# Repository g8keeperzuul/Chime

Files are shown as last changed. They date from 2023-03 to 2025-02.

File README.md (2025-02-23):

# Chime : A Home Assistant Siren Implementation #

## Description ##

The **Chime** is the second half of the smart doorbell project. However, the Chime (or Siren in Home Assistant nomanclature) can exist independently of the Doorbell. Any home automation task that can benefit from an alarm or audio annoucement and display some status information would find a use for the Chime.

The doorbell essentially provides a button to trigger an action in Home Assistant. Through the magic of some scripted automation, HA then commands the Chime to make a doorbell sound. The doorbell and chimer are two separate independent projects which rely on HA to work together.

Of course, the chime need not be limited to doorbell only activities. Since it can play a variety of tones, or in fact any audio file, the Chime can also be used as a fire/smoke alarm and security siren. It can even welcome you home if you're using presence detection. 

_This project will detail the build of the Chime, a Home Assistant Siren implementation._

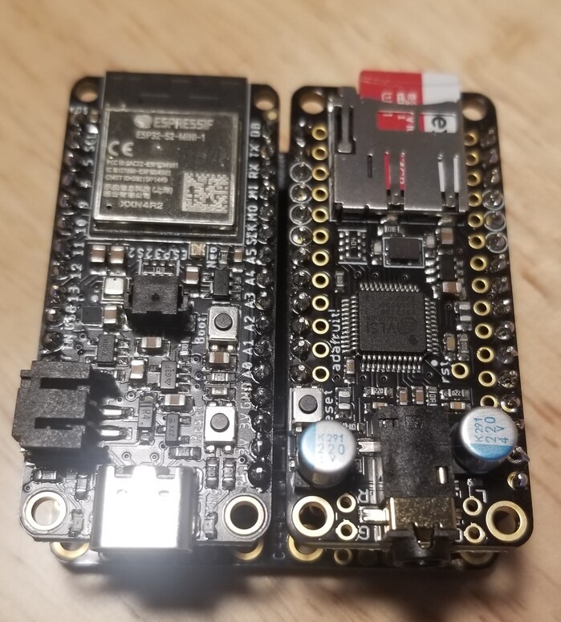
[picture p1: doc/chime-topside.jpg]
Chime top


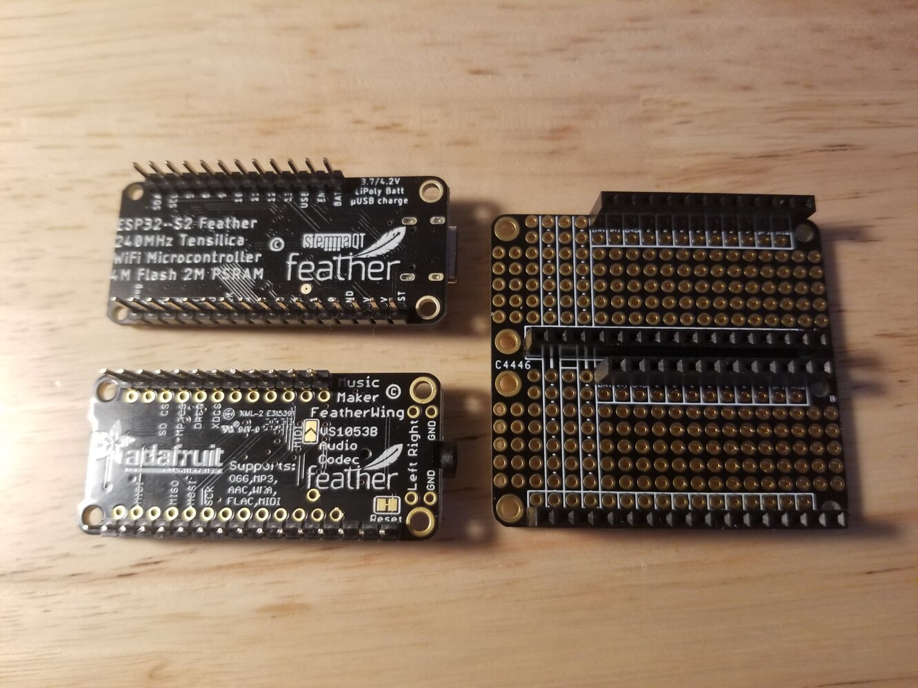
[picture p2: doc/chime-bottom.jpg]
Chime bottom


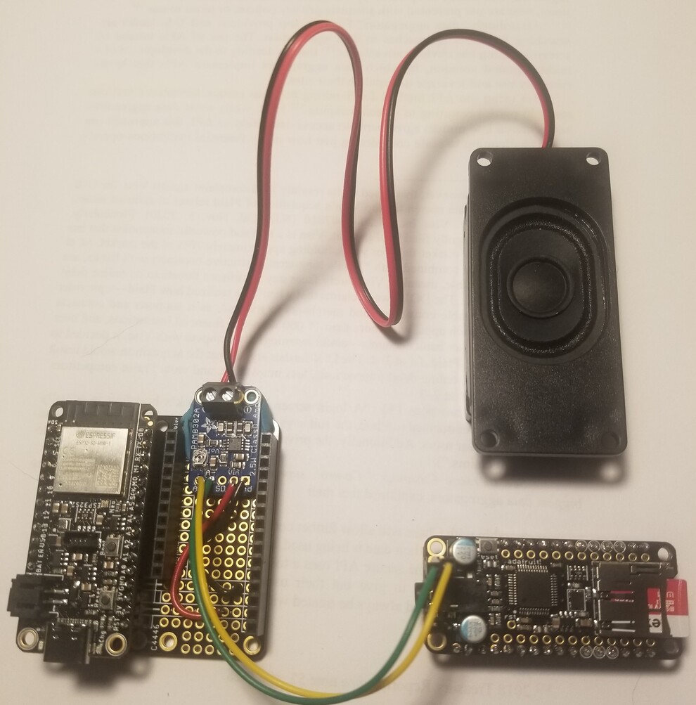
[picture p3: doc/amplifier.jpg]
Amp and Speaker


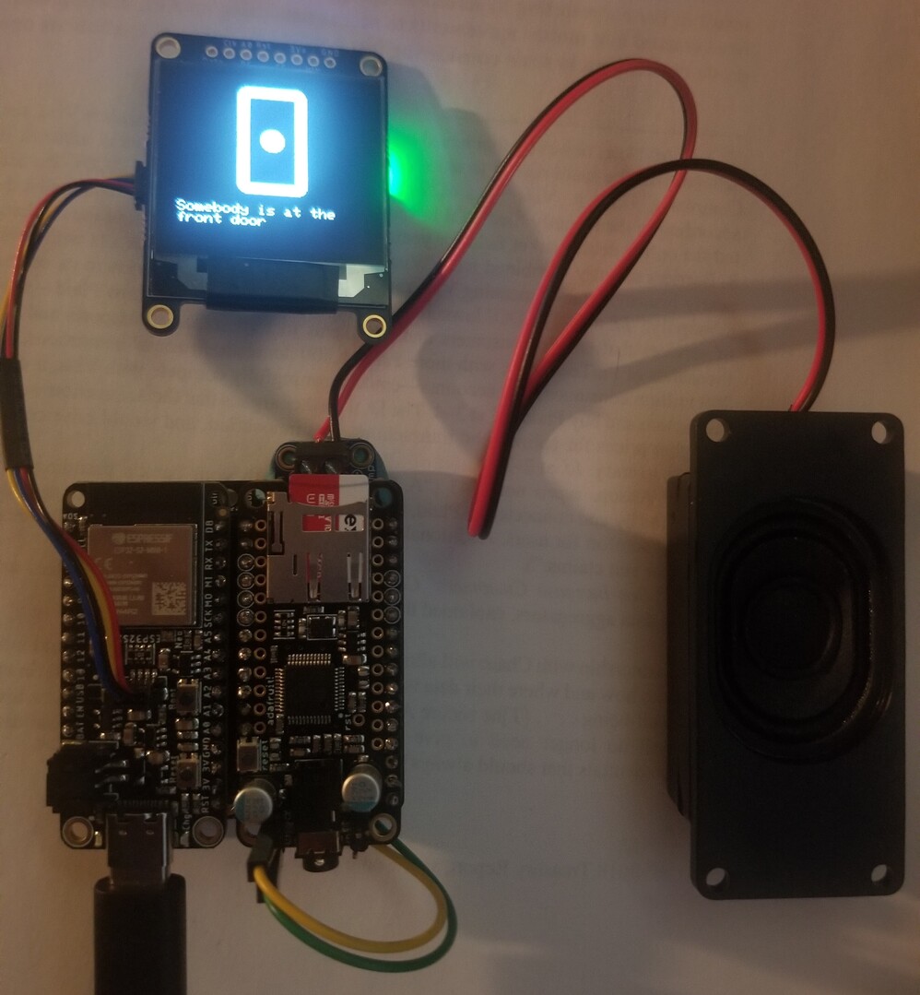
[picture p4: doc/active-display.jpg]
Active display


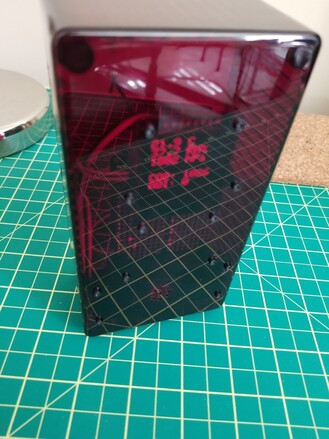
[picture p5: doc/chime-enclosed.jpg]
Chime enclosure


## Parts List ##
| Component | Description |
| -- | -- |
| [Adafruit ESP32-S2 Feather with BME280](https://www.adafruit.com/product/5303) | An ESP32-S2 with 4MB Flash and 2MB PSRAM on a Feather format breakout. The BME280 temperature/humidity/pressure sensor is not necessary |
| [Adafruit MusicMaker Featherwing](https://www.adafruit.com/product/3357) | A Feather format breakout for the VS1053B, an encoding/decoding (codec) chip that can decode a wide variety of audio formats such as MP3, AAC, Ogg Vorbis, WMA, MIDI, FLAC, WAV (PCM and ADPCM) | 
| [FeatherWing Doubler](https://www.adafruit.com/product/2890) | Not strictly necessary since the two above Feather-formatted boards can be stacked on top of each other. However the FeatherWing Doubler with its side-by-side layout just allows easier access to buttons and SD card |
| [Adafruit Grayscale 1.5" 128x128 OLED Display](https://www.adafruit.com/product/4741)|An I2C enabled OLED 128x128 pixel display|
| [Adafruit Mono 2.5W Class D Audio Amplifier - PAM8302](https://www.adafruit.com/product/2130) | A 2.5 watt audio amplifier. |
| [Mono Enclosed Speaker - 3W 4 Ohm](https://www.adafruit.com/product/3351) | A simple speaker |

### Pin Mapping ###
When both the microcontroller and codec are on Feather breakouts, you simply stack one on top of the other and all the proper pins align. However, in case you don't have the convenience of having both components in a Feather breakout format, the pin connections between the microcontroller and codec are specified below:
| ESP32-S2 GPIO pins | MusicMaker IO pins | DEFINE (chime.h) | PAM8302 |
| -- | -- | -- | -- |
| 10 | XDCS (command/data select) | VS1053_DCS | |
| 9 (hardware interrupt capable pin - they all are on the ESP32)| DREQ (data request) | VS1053_DREQ | |
| 6 | VS1053 select | VS1053_CS | |
| 5 | SDCS (sdcard select) | CARDCS | |
| 36 (SCK) | SCK | | |
| 35 (MO) | MOSI | | |
| 37 (MI) | MISO | | |
| | G(round) near headphone jack | | A- |
| | R(ight) near headphone jack | | A+ |

## Assembly ##
Placing the ESP32-S2 Feather and MusicMaker onto the FeatherWing Doubler as well as plugging in the I2C display is all plug-and-go.
I should have bought the [version of the MusicMaker without the headphone jack](https://www.adafruit.com/product/3436) that can be connected directly to speakers (if you use this, you can forego the separate PAM8302 amplifier). As a work-around, I added the PAM8302 based audio amplifier which as you can see from the photos is blue-tacked beneath the MusicMaker, connected to 3.3V and ground as well as one of the channel outputs (to support stereo another PAM8302 amplifier and speaker would be required).

## SDCard ##
Format as FAT16 or FAT32. Create a directory to store all the tones you intend on using. The filenames will need to be in 8.3 format. The default directory is /tones (defined in chime.h). This directory should *ONLY* contain audio files that are compatible with the VS1053B codec (Ogg Vorbis, MP3/MP2/MP1, MP4, AAC, WMA, FLAC, WAV (PCM and ADPCM)). 

## MQTT Discovery ##
The Chime publishes several MQTT discovery messages upon startup.
The main one describes the [**siren**](https://www.home-assistant.io/integrations/siren.mqtt/) entity, providing the command topic to send messages to for activation/deactivation. Siren features such as duration, volume and available tones are also defined.
Available tones is dynamically populated with all files found in the /tones directory on the SD card. Calling the Siren service in Home Assistant will only allow one of the available tones to be set. 

### Siren: ###
Discovery topic: homeassistant/siren/featheresp32s2/chime/config
```
{
  "entity_category": "config",
  "unit_of_measurement": "",
  "availability_topic": "homeassistant/siren/featheresp32s2/availability",
  "unique_id": "featheresp32s2_chime",
  "device": {
    "name": "Chime",
    "identifiers": "84:F7:03:D6:8B:20",
    "mf": "Adafruit",
    "mdl": "Feather ESP32-S2 with BME280",
    "sw": "20230304.1700"
  },
  "name": "featheresp32s2 chime",
  "icon": "mdi:bullhorn",
  "state_topic": "homeassistant/siren/featheresp32s2/state",
  "command_topic": "homeassistant/siren/featheresp32s2/command",
  "optimistic": false,
  "support_duration": false,
  "support_volume_set": true,
  "available_tones": [
    "alarm.mp3",
    "alarm.wav",
    "bell.wav",
    "doorbell.wav",
    "siren001.wav",
    "siren002.wav",
    "siren003.wav"
  ]
}
```
Note that the "featheresp32s2" part of all the topics can be changed by editing DEVICE_ID in chime.h

### Text: ###
The [**text**](https://www.home-assistant.io/integrations/text.mqtt/) integration was just recently (Dec 2022) introduced. Be sure to update Home Assistant for support.

Discovery topic: homeassistant/text/featheresp32s2/display/config
```
{
  "entity_category": "config",
  "unit_of_measurement": "",
  "availability_topic": "homeassistant/siren/featheresp32s2/availability",
  "unique_id": "featheresp32s2_display",
  "device": {
    "name": "Chime",
    "identifiers": "84:F7:03:D6:8B:20",
    "mf": "Adafruit",
    "mdl": "Feather ESP32-S2 with BME280",
    "sw": "20230317.0900"
  },
  "name": "featheresp32s2 display",
  "icon": "mdi:image-text",
  "state_topic": "homeassistant/text/featheresp32s2/display/state",
  "command_topic": "homeassistant/text/featheresp32s2/display/command",
  "command_template": "{ 'text': '{{ value }}', 'graphic': 'NONE' }",
  "value_template": "{{ value_json.text }}"
}
```

Chime publishes some diagnostic information periodically, namely wifi related details such as RSSI value (measurable), IP and MAC addresses (static) to the topic *homeassistant/siren/featheresp32s2/diagnostics*

The diagnostic message is simply:
```
{
  "wifi_rssi": -50,
  "wifi_ip": "10.0.0.177",
  "wifi_mac": "84:F7:03:D6:8B:20",
  "last_boot": "2023-03-17T12:42:13-0400"
}
```

The MQTT discovery message for RSSI looks like this:
```
{
  "state_class": "measurement",
  "entity_category": "diagnostic",
  "availability_topic": "homeassistant/siren/featheresp32s2/availability",
  "unique_id": "featheresp32s2_wifi_rssi",
  "device": {
    "name": "Chime",
    "ids": "84:F7:03:D6:8B:20"
  },
  "name": "featheresp32s2 wifi_rssi",
  "icon": "mdi:wifi-strength-2",
  "state_topic": "homeassistant/siren/featheresp32s2/diagnostics",
  "value_template": "{{ value_json.wifi_rssi }}"
}
```
(last boot, IP and MAC discovery messages not shown)

The **refresh rate** is the frequency (in minutes) what the diagnostic information is updated.
The refresh rate can be set and it is made discoverable through the following message:

```
{
  "entity_category": "config",
  "unit_of_measurement": "minutes",
  "availability_topic": "homeassistant/siren/featheresp32s2/availability",
  "unique_id": "featheresp32s2_refreshrate",
  "device": {
    "name": "Chime",
    "identifiers": "84:F7:03:D6:8B:20",
    "mf": "Adafruit",
    "mdl": "Feather ESP32-S2 with BME280",
    "sw": "20230304.1700"
  },
  "name": "featheresp32s2 refreshrate",
  "icon": "mdi:refresh-circle",
  "state_topic": "homeassistant/number/featheresp32s2/refreshrate/get",
  "command_topic": "homeassistant/number/featheresp32s2/refreshrate/set",
  "min": 1,
  "max": 60,
  "step": 1
}
```

# Usage #

Once configured, the Chime should announce itself to Home Assistant without any further effort and be ready to incorporate into your automation scripts.

1. Copy sample-env.h to env.h and customize env.h and chime.h to match your environment.
2. (Optional) #define DISABLE_SERIAL_OUTPUT 1 in log.h to disable all serial logging. Best to keep logging enabled until everything is confirmed working. 
3. Compile and upload firmware to your device.
4. Format an SDcard with FAT16 or FAT32. Create a directory named **/tones** and copy some mp3 or wav files (using 8.3 filenames) into the directory. Insert the SDcard into the MusicMaker.
5. Power on device. Confirm through MQTT explorer that new discovery topics exist and that device is visible to Home Assistant.
6. Using *Home Assistant > Developer Tools > Services*, activate the siren. Note that only a tone listed in **available_tones** in the siren discovery message is allowed.

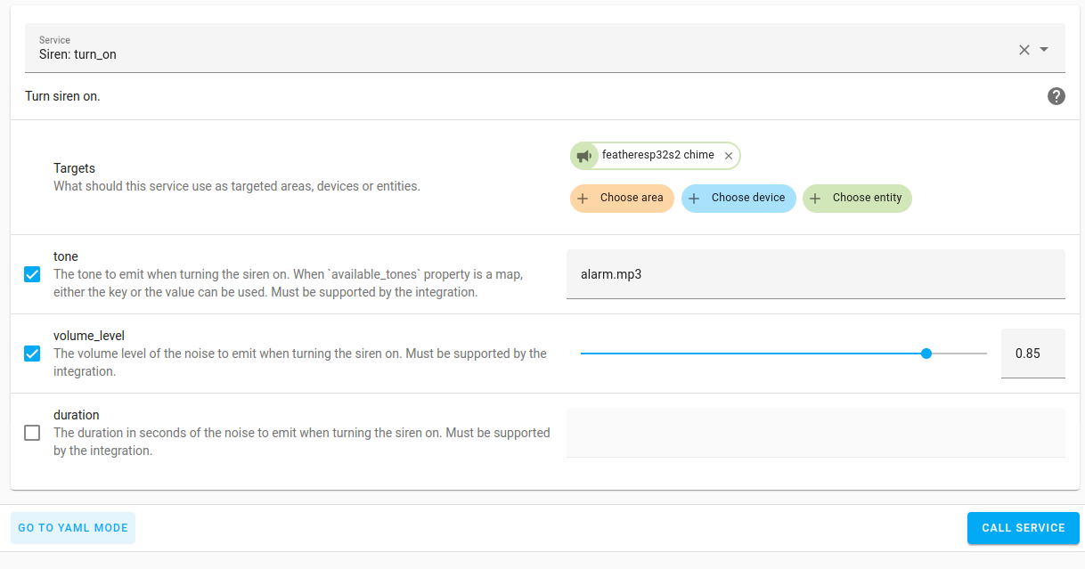
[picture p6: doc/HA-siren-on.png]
Activate Siren Service in HA


7. Alternatively publishing a message to MQTT will also turn the siren on and off: 
   
   *homeassistant/siren/featheresp32s2/command*
   ```
   {"state": "ON", "tone": "alarm.mp3", "volume_level": 0.5}
   {"state": "OFF"}
   ```
   where **volume_level** is a number between 0..1

   Received commands are reflected back to the state topic: 
   *homeassistant/siren/featheresp32s2/state*
  
8. The display is updated independently of the Siren.
 
  [Supported graphics](include/graphics.h) are: 
  | Label | Suggested Purpose | Graphic |
  | -- | -- | -- |
  | FIRE | Fire or smoke alarm |Fire |
  | WATER | Water leak | Water |
  | CO2 | Unsafe carbon dioxide levels | CO2 |
  | GAS | Unsafe gas detected | Gas |
  | AQI | Dirty air/particulate levels unsafe | CO2 |
  | ALERT | General alert | Alert |
  | DOOR | Doorbell ringer | Door |
  | GARAGE | Garage door ajar | Garage |
  | INFO | Informational | Info |
  | RADS | Unsafe radiation levels | Rads |
  | SAFE | Security alert | Safe |
  | FREEZE | Freeze warning | Freeze |

   *homeassistant/text/featheresp32s2/display/command*
   ```
    {"text": "Master bedroom carbon dioxide levels too high!", "graphic": "CO2" }

    {"text": "", "graphic": "NONE" } (for a blank screen)

    {"text": "...", "graphic": "MEDIUM_TEXT" } (for 10 characters, 6 lines)

    {"text": "...", "graphic": "LARGE_TEXT" } (for 7 characters, 5 lines)
   ```
## Customizing Graphics ##

1. Find something a [Material Design Icon](https://pictogrammers.com/library/mdi/) you like.
2. Edit the icon, by sizing it (remember the display maximum is 128x128) and setting a solid black background and white foreground colors.
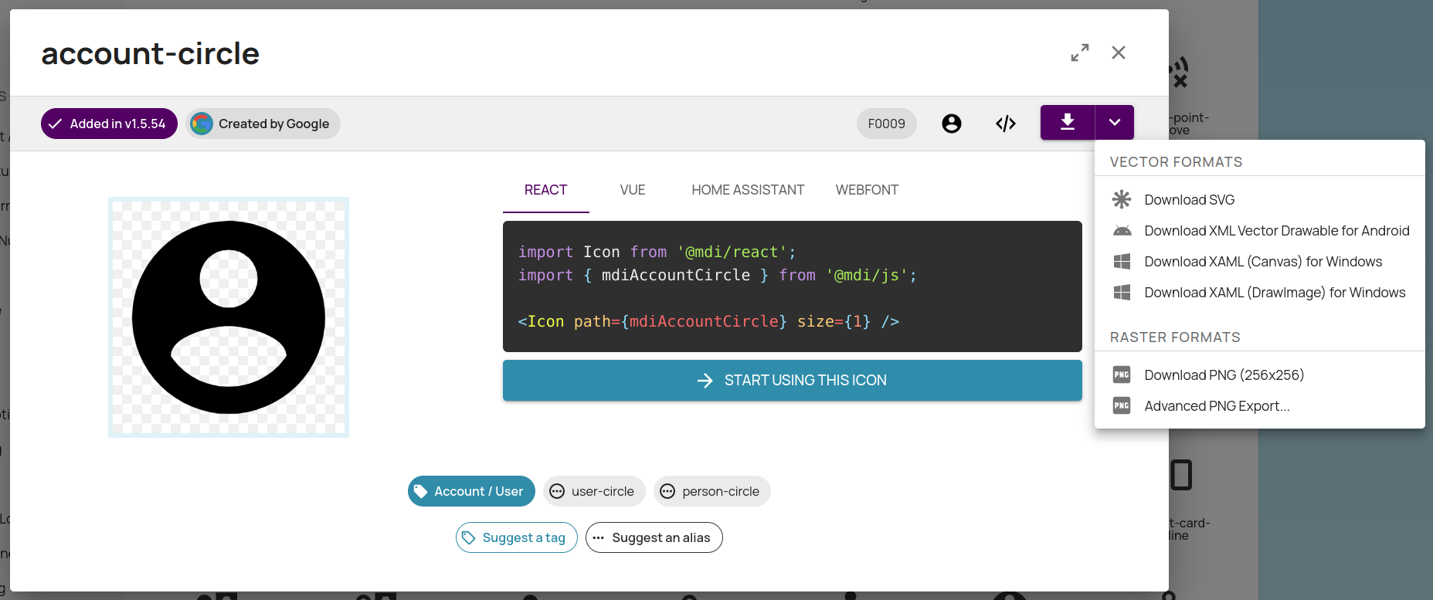
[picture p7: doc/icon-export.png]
Select icon for export
   
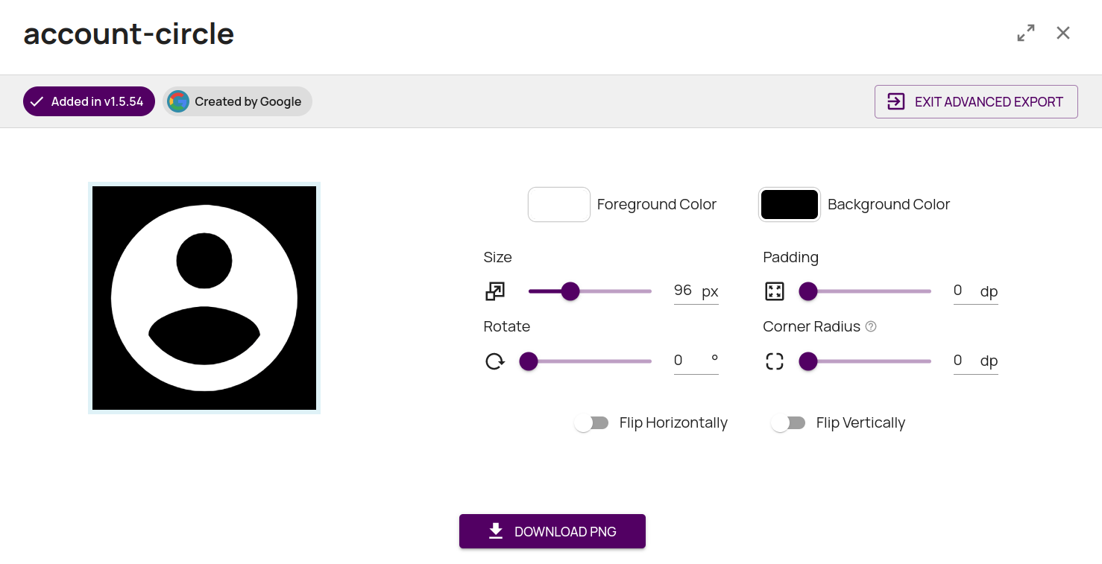
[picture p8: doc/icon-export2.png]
Edit icon
   
3. Once the graphic is created and available locally, you can upload it to a [website](https://notisrac.github.io/FileToCArray/) that will create a binary array for you.

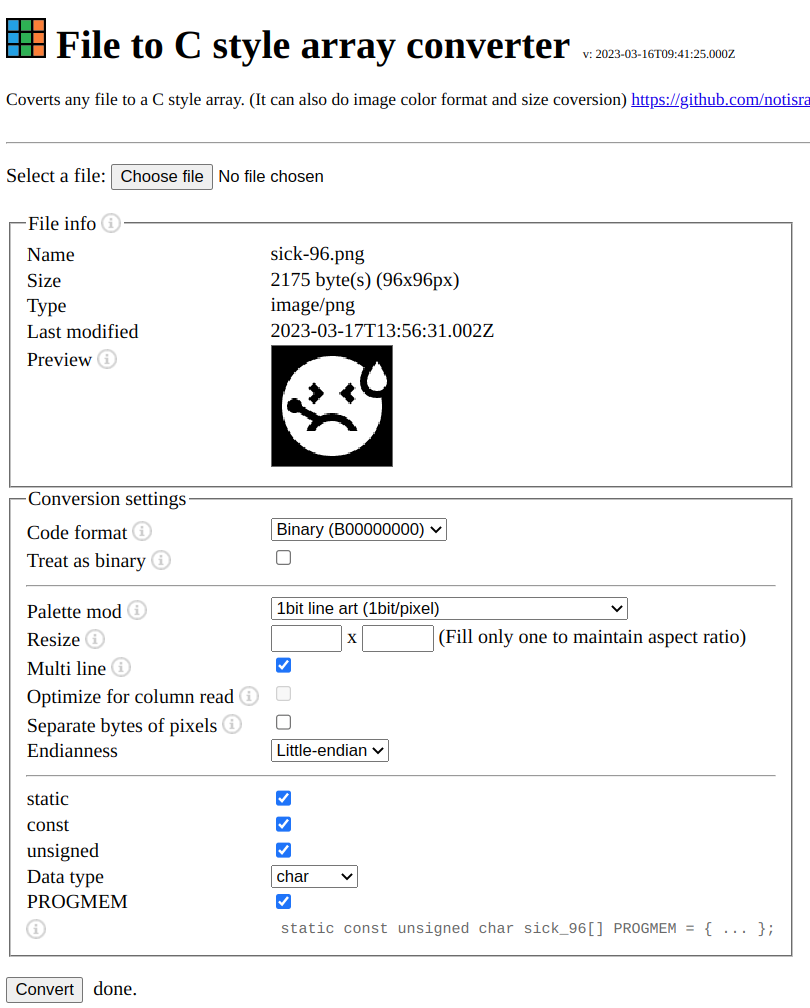
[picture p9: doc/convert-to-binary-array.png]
Create binary array

  
  The resulting output can be pasted directly into the [code](include/graphics.h).

## Home Assistant Integration ##

Of course the Chime integrates with HA using MQTT Discovery messages. However this section discusses how HA acts as the glue between the doorbell and the chime, so that pressing the doorbell button ultimately results in a ring tone sounded by the chime. 
The doorbell project captures a photo and uploads it to HA. This state update can be used as a trigger for an HA automation. Notice that the action associated with this trigger is a script.

In **automations.yaml**:
```

- id: "DOORBELL_ACTIVATED"
  alias: "Doorbell activated"
  description: "Trigger doorbell tone on Siren when Doorbell activated"
  trigger:
    - entity_id: camera.doorbell_snapshot      
      platform: state
      attribute: file_path # trigger on any change to attribute
  condition: []
  action:
    service: script.doorbell_activated
```

The script can be thought of as simply a macro for some grouped activities.

In **scripts.yaml**:
```
doorbell_activated:
  alias: Doorbell pressed
  icon: mdi:doorbell
  description: Plays the doorbell tone and displays the doorbell message, cleared
    after 1 minute
  mode: queued
  max: 5
  max_exceeded: info
  sequence:
  - alias: Display doorbell ringing message
    service: mqtt.publish
    data:
      topic: homeassistant/text/featheresp32s2/display/command
      retain: false
      payload: '{"text":"Somebody is at the   front door", "graphic": "DOOR" }'
  - alias: Play doorbell tone
    service: mqtt.publish
    data:
      topic: homeassistant/siren/featheresp32s2/command
      retain: false
      payload: '{"state":"ON", "tone": "doorbell.wav", "volume_set": 0.75 }'
  - alias: Doorbell notification
    service: notify.notify
    data:
      message: Doorbell rung!
  - alias: Wait
    delay:
      minutes: 1
  - alias: Clear display
    service: mqtt.publish
    data:
      topic: homeassistant/text/featheresp32s2/display/command
      retain: false
      payload: '{"text":"", "graphic": "NONE" }'
  ```
### Sequence Diagram ###

This sequence illustrates how both the Doorbell project and Chime project work together through Home Assistant automation. 

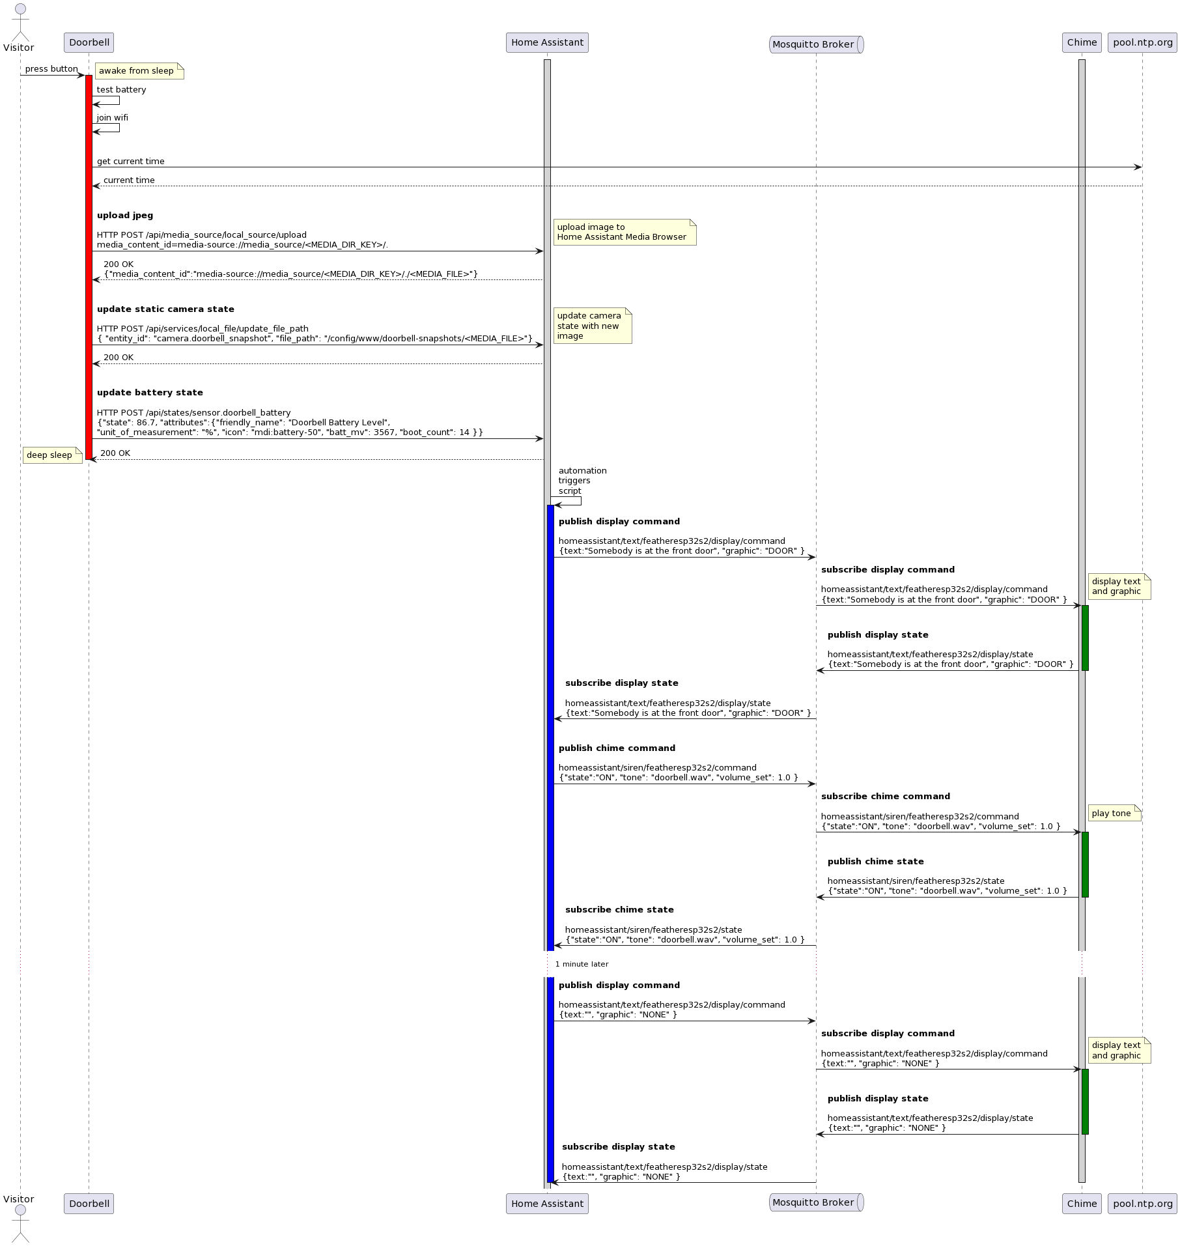
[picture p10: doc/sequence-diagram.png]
Doorbell + Chime flow

Generated using [PlantUML](https://www.plantuml.com/plantuml/png/rLLHRzis47xdhpYes5jZfUtQ3KONj5qoD6WJ5sqmO801WPBE4bkHLCYJFIF9Vnz9IL6apKk303Ec9_FutTrttntFRonnGusi6ECPQGFjzxkmOZY5ZrjOjrPMEnUHYPe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)

**PlantUML for Sequence Diagram**
```
@startuml

actor       Visitor            as visitor
participant Doorbell           as doorbell
participant "Home Assistant"   as ha
queue       "Mosquitto Broker" as mqtt
participant Chime              as chime
participant pool.ntp.org       as ntp

activate ha #lightgray
activate chime #lightgray

visitor -> doorbell : press button 
note right
awake from sleep
end note
activate doorbell #red

doorbell -> doorbell : test battery
doorbell -> doorbell : join wifi

|||
doorbell -> ntp : get current time
ntp --> doorbell : current time
|||

doorbell -> ha : <b>upload jpeg\n\nHTTP POST /api/media_source/local_source/upload\nmedia_content_id=media-source://media_source/<MEDIA_DIR_KEY>/.
note right
upload image to
Home Assistant Media Browser
end note

ha --> doorbell : 200 OK\n{"media_content_id":"media-source://media_source/<MEDIA_DIR_KEY>/./<MEDIA_FILE>"}
|||
doorbell -> ha : <b>update static camera state\n\nHTTP POST /api/services/local_file/update_file_path\n{ "entity_id": "camera.doorbell_snapshot", "file_path": "/config/www/doorbell-snapshots/<MEDIA_FILE>"}
note right
update camera
state with new 
image
end note
ha --> doorbell : 200 OK
|||
doorbell -> ha : <b>update battery state\n\nHTTP POST /api/states/sensor.doorbell_battery\n{"state": 86.7, "attributes":{"friendly_name": "Doorbell Battery Level",\n"unit_of_measurement": "%", "icon": "mdi:battery-50", "batt_mv": 3567, "boot_count": 14 }}
ha --> doorbell : 200 OK
deactivate doorbell

note left
deep sleep
end note

ha -> ha : automation\ntriggers\nscript
activate ha #blue

ha -> mqtt : <b>publish display command\n\nhomeassistant/text/featheresp32s2/display/command\n{text:"Somebody is at the front door", "graphic": "DOOR" }

mqtt -> chime : <b>subscribe display command\n\nhomeassistant/text/featheresp32s2/display/command\n{text:"Somebody is at the front door", "graphic": "DOOR" }
activate chime #green
note right
display text
and graphic
end note
|||
chime -> mqtt : <b>publish display state\n\nhomeassistant/text/featheresp32s2/display/state\n{text:"Somebody is at the front door", "graphic": "DOOR" }

deactivate chime

mqtt -> ha : <b>subscribe display state\n\nhomeassistant/text/featheresp32s2/display/state\n{text:"Somebody is at the front door", "graphic": "DOOR" }
|||
ha -> mqtt : <b>publish chime command\n\nhomeassistant/siren/featheresp32s2/command\n{"state":"ON", "tone": "doorbell.wav", "volume_set": 1.0 }

mqtt -> chime : <b>subscribe chime command\n\nhomeassistant/siren/featheresp32s2/command\n{"state":"ON", "tone": "doorbell.wav", "volume_set": 1.0 }
activate chime #green
note right
play tone
end note
|||
chime -> mqtt : <b>publish chime state\n\nhomeassistant/siren/featheresp32s2/state\n{"state":"ON", "tone": "doorbell.wav", "volume_set": 1.0 }

deactivate chime

mqtt -> ha : <b>subscribe chime state\n\nhomeassistant/siren/featheresp32s2/state\n{"state":"ON", "tone": "doorbell.wav", "volume_set": 1.0 }

...1 minute later...

ha -> mqtt : <b>publish display command\n\nhomeassistant/text/featheresp32s2/display/command\n{text:"", "graphic": "NONE" }

mqtt -> chime : <b>subscribe display command\n\nhomeassistant/text/featheresp32s2/display/command\n{text:"", "graphic": "NONE" }
activate chime #green
note right
display text
and graphic
end note
|||
chime -> mqtt : <b>publish display state\n\nhomeassistant/text/featheresp32s2/display/state\n{text:"", "graphic": "NONE" }

deactivate chime

mqtt -> ha : <b>subscribe display state\n\nhomeassistant/text/featheresp32s2/display/state\n{text:"", "graphic": "NONE" }

deactivate chime
deactivate chime

deactivate ha

@enduml
```

## Display Continuous Updates using Home Assistant Automation ##

Rather than only show alerts or events (like a doorbell press), Chime can also be used to continuously display sensor updates.
In this example, environmental sensors from the [AirMonitor project](https://github.com/g8keeperzuul/AirMonitor) are displayed on Chime as they are updated.
The Chime display is updated via a message published to MQTT with the various sensor values used as parameters to the message body.

```
alias: Update Chime on Air Monitor
description: Display Air Monitor (featherM0) status on Chime
trigger:
  - platform: state
    entity_id:
      - sensor.featherm0_aqi
      - sensor.featherm0_carbon_dioxide
      - sensor.featherm0_humidity
      - sensor.featherm0_pressure
      - sensor.featherm0_temperature
condition: []
action:
  - service: mqtt.publish
    data:
      qos: 0
      retain: false
      topic: homeassistant/text/featheresp32s2/display/command
      payload: >-
        { "text": "{{states('sensor.featherm0_temperature')|round(1)}}
        C\n{{states('sensor.featherm0_humidity')|round(1)}}
        RH%\n{{states('sensor.featherm0_pressure')|round()}} hPa\n\nCO2:
        {{states('sensor.featherm0_carbon_dioxide')}}\nAQI:
        {{states('sensor.featherm0_aqi')}}", "graphic": "MEDIUM_TEXT" }
mode: single
```
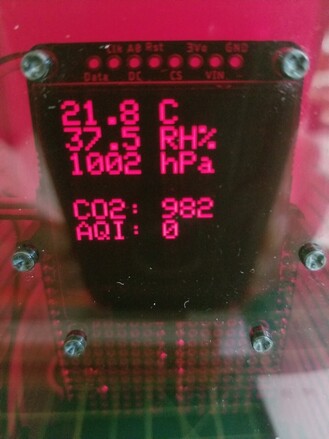
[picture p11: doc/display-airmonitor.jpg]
Chime displaying AirMonitor results


## Display Continuous Updates without Home Assistant ##

The Chime is a dumb device that has no sensors of its own. It takes commands to display text and graphic or play some audio and nothing more.
The commands are provided via MQTT topics that Chime subscribes to. 

In this scenario, a simple Python program acts as an intermediary. It subscribes to topics which various sensors publish their telemetry to. It then formats that data for display on Chime and publishes commands to it. 
This way Chime can cycle through a number of different sensors displaying the latest reading from each of them in turn. 
The Python program provides more power and flexibility than Home Assistant Automations, but it does require all data that it needs to be published to an MQTT topic. 

The following Python program and accompanying optional Dockerfile provides this functionality without any need for Home Assistant at all. 

   [Python program mqtt2chime.py](mqtt2chime/src/mqtt2chime.py)

   Running this simple program within a Docker container is completely optional.
   To build a docker image with mqtt2chime, simply run the script [build_docker_image.sh](mqtt2chime/src/build_docker_image.sh)
   With the docker image built, run it with the following command:
   ```
   docker run -d --name mqtt2chime g8keeperzuul/mqtt2chime:latest --broker MQTT_BROKER_HOSTNAME --port 1883 --user USERNAME --pass PASSWORD -v
   ```

## Enclosure ##

A small Art Deco radio inspired case was design and 3D printed. 
The idea came from this [Art Deco weather forcast display](https://www.thingiverse.com/thing:1964380), with modifications made to support the mounting of the square screen in a circular hole. 

1. [3D STL model - face](content/3d-model/Chime-face.stl)
2. [3D STL model - enclosure](content/3d-model/Chime-Body.stl)
3. [3D STL model - screen mount](content/3d-model/Chime%20screen%20mount.stl)

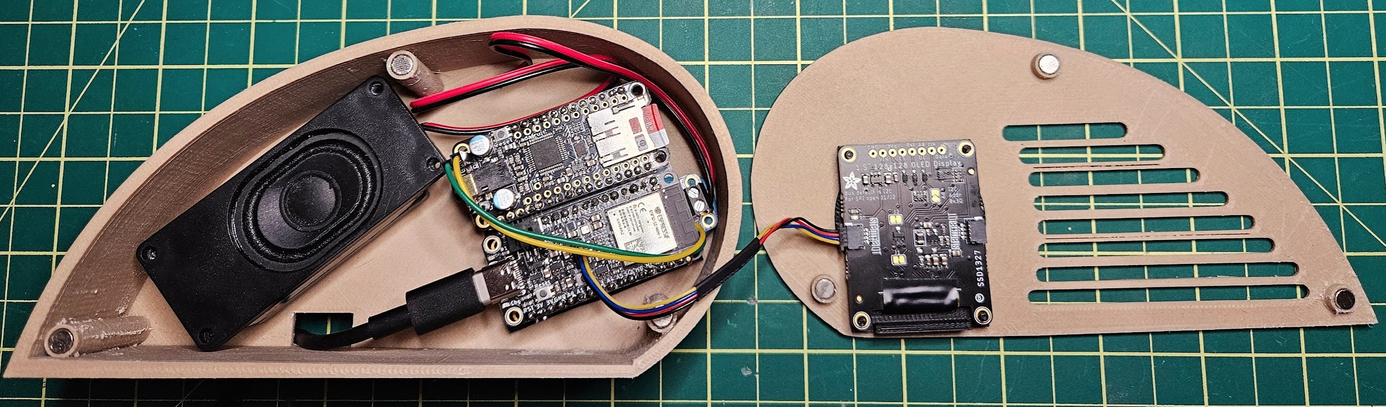
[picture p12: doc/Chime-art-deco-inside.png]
Finished - open


Note the use of magnets to affix the face to the main enclosure.
What is not well illustrated is the screen mount. It friction fits the display into the circular hole. In the example, it is printed with black filament so that it blends with the black display. 

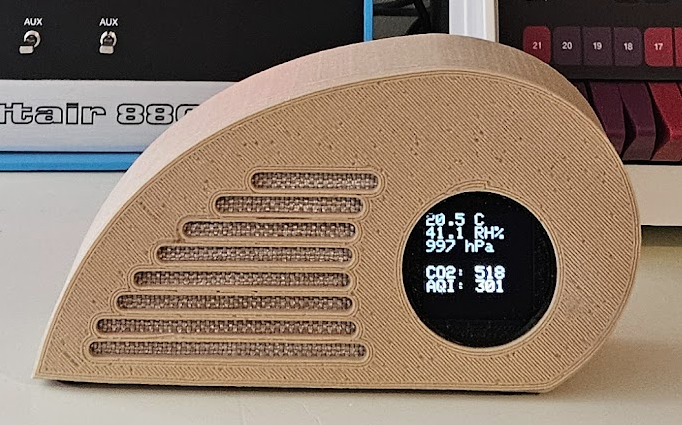
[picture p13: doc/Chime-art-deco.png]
Finished - closed


## Future Enhancements ##

1. Automatically clear the display after a specified duration. Default would be to display forever.
2. Loop play for duration (which is already a supported parameter for 'siren').
3. Center-justify text.

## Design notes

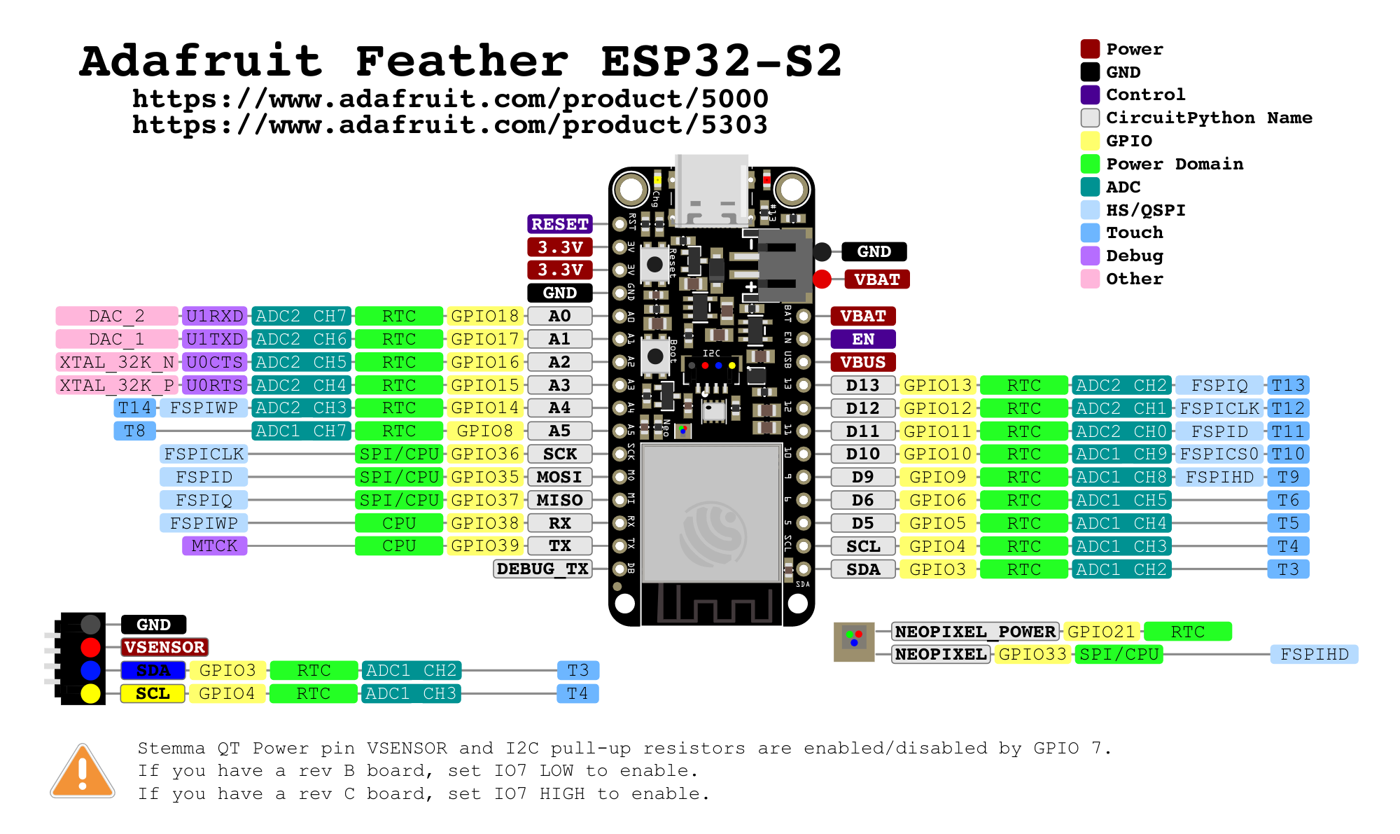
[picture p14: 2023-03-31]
doc/Adafruit-Feather-ESP32-S2-pinout.png

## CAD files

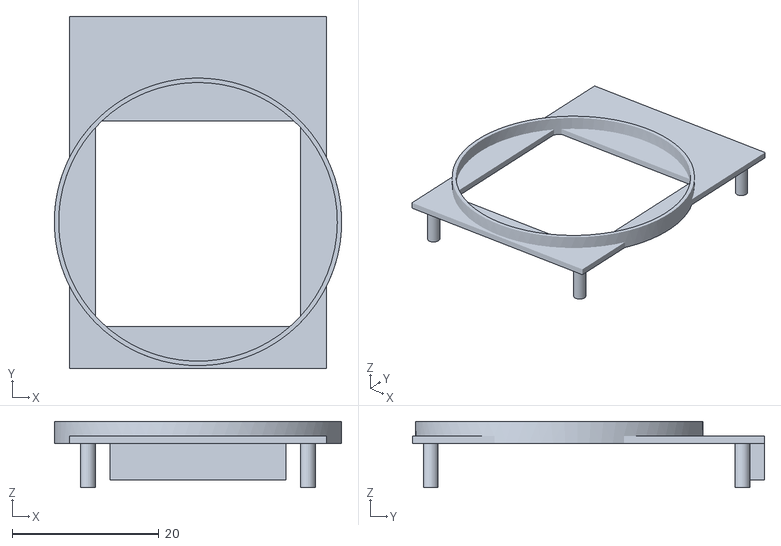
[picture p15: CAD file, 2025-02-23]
content/3d-model/Chime screen mount.stl
39.2 x 48.0 x 9.00

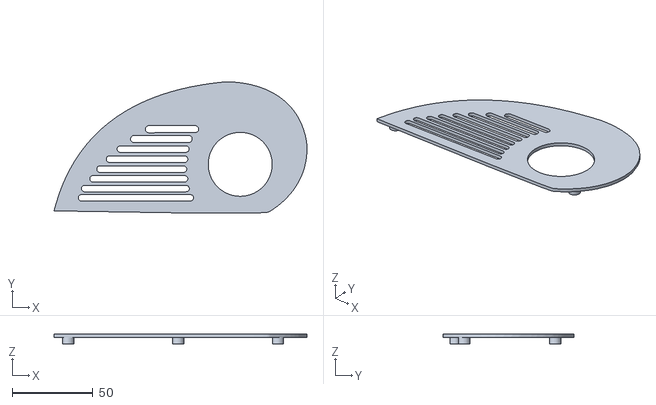
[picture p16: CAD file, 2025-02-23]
content/3d-model/Chime-face.stl
156.7 x 81.2 x 6.00

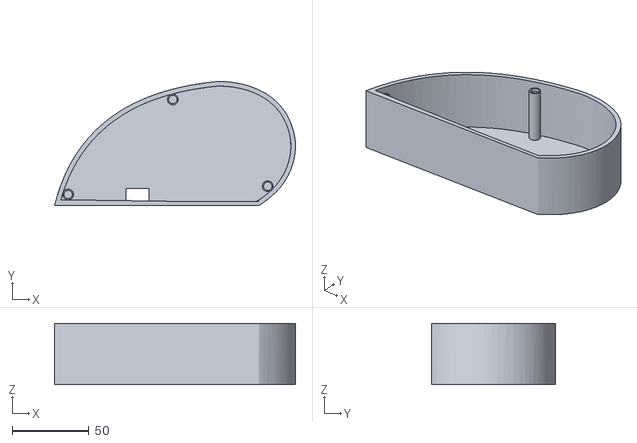
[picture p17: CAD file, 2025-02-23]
content/3d-model/Chime-Body.stl
156.9 x 80.7 x 40.0

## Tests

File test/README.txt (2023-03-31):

To simulate to Home Assistant what messages the device sends to MQTT:

Run first

    Upon device setup(), publishes MQTT discovery message
    siren/discovery-chime.sh  <<< this simulates what the device would publish to MQTT 
    text/discovery-display.sh <<< this simulates what the device would publish to MQTT

Then 
  Siren:
    Device receives ON command (subscribes to homeassistant/siren/featheresp32s2/command topic), and 
    reflects ON status (publishes to homeassistant/siren/featheresp32s2/status topic).
    siren/send_ON_command.sh
    siren/publish_ON_status.sh <<< this simulates what the device would publish to MQTT

    Device receives OFF command (subscribes to homeassistant/siren/featheresp32s2/command topic), and 
    reflects OFF status (publishes to homeassistant/siren/featheresp32s2/status topic)
    siren/send_OFF_command.sh
    siren/publish_OFF_status.sh <<< this simulates what the device would publish to MQTT

  Text:
    Device receives command (subscribes to homeassistant/text/featheresp32s2/display/command topic), and 
    reflects status (publishes to homeassistant/text/featheresp32s2/display/status topic).
    text/send_FIRE_command.sh
    text/publish_FIRE_status.sh <<< this simulates what the device would publish to MQTT

    To turn off the display, the device receives the command (subscribes to homeassistant/text/featheresp32s2/display/command topic), and 
    reflects status (publishes to homeassistant/text/featheresp32s2/display/status topic).
    text/send_display_command.sh "NONE" ""

Home Assistant provides a service where the Siren can be turned ON/OFF or toggled

Calling the below service results in the MQTT publication of {state: ON, tone: alarm, duration: 10, volume_set: 1.0}
Note that the data is 'volume_level', but the parameter is 'volume_set'.
Volume is from 0.0 to 1.0
The service will ONLY allow tones that have been pre-defined by available_tones:[doorbell,alarm] defined during discovery.

service: siren.turn_on
data:
  tone: alarm
  volume_level: 1
  duration: "10"
target:
  entity_id: siren.featheresp32s2_chime

In configuration.yaml, re-label the default labels.

customize:
  number.featheresp32s2_refreshrate:
    friendly_name: Refresh Rate
  sensor.featheresp32s2_last_boot:
    friendly_name: Last Boot
  sensor.featheresp32s2_wifi_ip:
    friendly_name: IP Address
  sensor.featheresp32s2_wifi_mac:
    friendly_name: MAC Address
  sensor.featheresp32s2_wifi_rssi:
    friendly_name: Wifi RSSI
  siren.featheresp32s2_chime:
    friendly_name: Chime Audio
  text.featheresp32s2_display:
    friendly_name: Chime Display

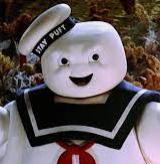
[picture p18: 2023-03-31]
test/fake_doorbell/staypuft.png

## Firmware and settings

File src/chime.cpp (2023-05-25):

/*
  *** Siren Integration ***

  Play tone on command.

  https://www.home-assistant.io/integrations/siren/
  https://developers.home-assistant.io/docs/core/entity/siren


  homeassistant/siren/featheresp32s2/command   <<< set state; device will subscribe to this topic
  homeassistant/siren/featheresp32s2/state     >>> get state; device will publish to this topic

  Both command and state receive or reture the same payload:
  {
    state: ON
    volume_level: 0.0..1.0,
    tone: [alarm.mp3|doorbell.wav],  FILE EXPECTED TO BE FOUND IN DIRECTORY TONE_DIR ON SDCARD
    duration: 0..n   NOT SUPPORTED
  }  
  OR
  {
    state: OFF
  }  

*** Text Integration ***

Display message on command. 

homeassistant/text/featheresp32s2/display/command <<< {"text":"Basement smoke detector triggered!", "graphic": "FIRE" }
homeassistant/text/featheresp32s2/display/command <<< {"text":"hello world", "graphic": "NONE" }  <<< "hello world" input from HA

homeassistant/text/featheresp32s2/display/state   >>> {"text":"Basement smoke detector triggered!", "graphic": "FIRE" }
homeassistant/text/featheresp32s2/display/state   >>> {"text":"hello world", "graphic": "NONE" }

To clear the display:
homeassistant/text/featheresp32s2/display/command <<< {"text":"", "graphic": "NONE" }
homeassistant/text/featheresp32s2/display/command <<< ""

The first is preferrable since it more clearly reflects the command back to state topic.
The second will actually result in the command and state topics begin deleted in the broker.

Supported Graphics:
NONE, DOOR, RADS, FIRE, INFO, AQI, CO2, WATER, GAS, FREEZE, ALERT, SAFE, GARAGE

*** Diagnostics ***

Publishes diagnostic information according to refresh frequency.

homeassistant/siren/featheresp32s2/diagnostics >>> { "wifi_rssi": -43, "wifi_ip": "10.0.0.177", "wifi_mac": "84:F7:03:D6:8B:20" }

*** Configuration *** 

Publication frequency in minutes.

homeassistant/number/featheresp32s2/refreshrate/get >>> 1
homeassistant/number/featheresp32s2/refreshrate/set <<< 1


********************************************************************************
DISCOVERY CONFIGURATION.YAML:

This is what the manual configuration for siren and text would look like. 
However it is unnecessary as the device sends auto-discovery MQTT messages upon startup.

mqtt:
  siren:
    - unique_id: featheresp32s2_chime
      name: "Chime"
      icon: "mdi:bullhorn"
      device: 
        name: "Chime"
        identifiers: "84:F7:03:D6:8B:20"
        mf: "Adafruit"
        mdl: "Feather ESP32-S2 with BME280"
        sw: "20230302.2100"      

      availability_topic: "homeassistant/siren/featheresp32s2/availability"
      
      state_topic: "homeassistant/siren/featheresp32s2/state"        
      state_value_template: "{{ value_json.state }}"
      state_on: "ON"
      state_off: "OFF"

      command_topic: "homeassistant/siren/featheresp32s2/command"  
      command_template: "{ 'state': '{{ value }}', 'tone': '{{ tone }}', 'volume_set': {{ volume_level }}, 'duration': {{ duration }} }"
      command_off_template": "{ 'state': '{{ value }}' }"
      payload_on: "ON"
      payload_off: "OFF"

      available_tones:
        - doorbell
        - alarm
      support_duration: true
      support_volume_set: true
      
      optimistic: false
      qos: 0
      retain: true

  mqtt:
    text:
      - unique_id: "featheresp32s2_display"
        name: "Chime display"
        icon: "mdi:image-text"
        min: 0
        max: 255
        availability_topic: "homeassistant/siren/featheresp32s2/availability"
        state_topic: "homeassistant/text/featheresp32s2/display/state"
        value_template: "{{ value_json.text }}"
        command_topic: "homeassistant/text/featheresp32s2/display/command"
        command_template: "{ 'text': '{{ value }}', 'graphic': 'NONE' }"
        optimistic: false
        device:
          name: "Chime"
          identifiers: "84:F7:03:D6:8B:20"
          mf: "Adafruit"
          mdl: "Feather ESP32-S2 with BME280"
          sw: "20230302.2100"      
*/

#include "chime.h"
#include "graphics.h"

// Time
const char* ntpServer = NTP_SERVER;
RTC_DATA_ATTR bool time_is_set = false;
char lastboot[80];  // yyyy-mm-ddThh:mm:ss[+|-]zzz  ISO8601

Adafruit_NeoPixel pixels(NUMPIXELS, PIN_NEOPIXEL);

Adafruit_BME280 bme; // I2C

Adafruit_VS1053_FilePlayer musicPlayer = Adafruit_VS1053_FilePlayer(VS1053_RESET, VS1053_CS, VS1053_DCS, VS1053_DREQ, CARDCS);

// 128x128 SSD1327 display connected via I2C
Adafruit_SSD1327 display(DISPLAY_WIDTH, DISPLAY_HEIGHT, &Wire, OLED_RESET, 1000000);
// software SPI
//Adafruit_SSD1327 display(128, 128, OLED_MOSI, OLED_CLK, OLED_DC, OLED_RESET, OLED_CS);
// hardware SPI
//Adafruit_SSD1327 display(128, 128, &SPI, OLED_DC, OLED_RESET, OLED_CS);

WiFiClient wificlient;
MQTTClient mqttclient(768); // default is 128 bytes;  https://github.com/256dpi/arduino-mqtt#notes

unsigned long refresh_rate = 60000; // 1 minutes default; frequency of sensor updates in milliseconds

/*
  Since the fully constructed list of discovery_config (topics and payloads) consumes considerable RAM, reduce it to just the facts.
  Generate each discovery_config one at a time at the point of publishing the message in order to conserve RAM.
  Once everything is successfully published, purge list contents (no longer needed).
*/
std::vector<discovery_metadata> discovery_metadata_list;                                            // list of data used to construct discovery_config for sensor discovery
std::vector<discovery_config_metadata> discovery_config_metadata_list;                              // list of data used to construct discovery_config for config/control discovery
std::vector<discovery_measured_diagnostic_metadata> discovery_measured_diagnostic_metadata_list;    // list of data used to construct discovery_config for sensor measured diagnostics (like RSSI)
std::vector<discovery_fact_diagnostic_metadata> discovery_fact_diagnostic_metadata_list;            // list of data used to construct discovery_config for fact diagnostics (like IP address)

// Last will and testament topic
const std::string AVAILABILITY_TOPIC = buildAvailabilityTopic("siren", std::string(DEVICE_ID)); // homeassistant/siren/featheresp32s2/availability

const std::string DIAGNOSTIC_TOPIC = buildDiagnosticTopic("siren", std::string(DEVICE_ID)); // homeassistant/siren/featheresp32s2/diagnostics

// All sensor updates are published in a single complex json payload to a single topic
const std::string STATE_TOPIC = buildStateTopic("siren", std::string(DEVICE_ID)); // homeassistant/siren/featheresp32s2/state

const std::string ON_VALUE = "ON";
const std::string OFF_VALUE = "OFF";

// *****************************

std::vector<std::string> availableTones(File dir){
  std::vector<std::string> tones = { }; 

  Sprintln("Found tones:");
  while(true) {     
     File entry =  dir.openNextFile();
     if(!entry) {
       // no more files       
       break;
     }
     if(!entry.isDirectory()){
      Sprint("\t"); Sprintln(entry.name());
      tones.push_back(entry.name());
     }   
     entry.close();
   }
  
  return tones;
}

/*
  device_class : https://developers.home-assistant.io/docs/core/entity/sensor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
                 https://www.home-assistant.io/integrations/sensor/#device-class
  has_sub_attr : true if you want to provide sub attributes under the main attribute
  icon : https://materialdesignicons.com/
  unit : (depends on device class, see link above)
*/
// build discovery message - step 1 of 4
std::vector<discovery_metadata> getAllDiscoveryMessagesMetadata(){
/*
  NOTE: SENSOR INACCURACY!
  
  These sensor are available as they are included with the BME280.
  However, the temperature (and hence humidity) sensors are wildly abnormal due to their proximity to the CPU.
  They can only be used during brief periods shortly after waking from >=5min sleep in order to obtain an accurate reading. 

  discovery_metadata temp, humidity, pressure;

  // default device_type = "sensor"
  // default sub_attr = false

  temp.device_class = "temperature";  
  temp.icon = "mdi:home-thermometer";
  temp.unit = "°C";

  humidity.device_class = "humidity";  
  humidity.icon = "mdi:water-percent";
  humidity.unit = "%";

  pressure.device_class = "pressure";
  pressure.icon = "mdi:gauge";
  pressure.unit = "hPa";
*/
  std::vector<discovery_metadata> dm = { /*temp, humidity, pressure*/ };  
  return dm;
}

// build discovery config/control message - step 1 of 4
std::vector<discovery_config_metadata> getAllDiscoveryConfigMessagesMetadata(){
  discovery_config_metadata refrate, siren, display;

  /*
  Dynamically build list of available tones from all files in /tones directory on SD card.
  */
  std::vector<std::string> tones = availableTones(SD.open(TONE_DIR));
  std::string custom_settings = "\"optimistic\": false, \"support_duration\": false, \"support_volume_set\": true, \"available_tones\": [";  
  bool first = true;
  for(int i=0;i < tones.size(); i++){
    if(first){
      first = false;
    }
    else{
      custom_settings.append(",");
    }
    custom_settings.append("\"");
    custom_settings.append(tones.at(i));
    custom_settings.append("\"");
  }
  custom_settings.append("]");

  siren.device_type = "siren";
  siren.control_name = "chime";
  //siren.custom_settings = "\"optimistic\": false, \"support_duration\": false, \"support_volume_set\": true, \"available_tones\": [\"doorbell.wav\", \"alarm.mp3\"]";
  siren.custom_settings = custom_settings;
  siren.icon = "mdi:bullhorn";
  siren.unit = ""; 
  // override default get/set topic names
  siren.set_topic = "homeassistant/siren/featheresp32s2/command";
  siren.get_topic = "homeassistant/siren/featheresp32s2/state";


  refrate.device_type = "number";
  refrate.control_name = "refreshrate";
  refrate.custom_settings = "\"min\": 1, \"max\": 60, \"step\": 1";
  refrate.icon = "mdi:refresh-circle";
  refrate.unit = "minutes";
  // default topic names if not specified
  //refrate.set_topic = "homeassistant/number/featheresp32s2/refreshrate/set";
  //refrate.get_topic = "homeassistant/number/featheresp32s2/refreshrate/get";

  display.device_type = "text";
  display.control_name = "display";
  display.custom_settings = "\"min\": 0, \"max\": 84"; // 255 is the max
  display.icon = "mdi:image-text";
  display.unit = "";
  // override default get/set topic names
  display.set_topic = "homeassistant/text/featheresp32s2/display/command"; // command payload= { "text": "Basement smoke detector triggered!", "graphic": "FIRE" }
  display.get_topic = "homeassistant/text/featheresp32s2/display/state"; // device reflects command payload to the state topic (same as above)
  display.custom_settings = "\"command_template\": \"{ 'text': '{{ value }}', 'graphic': 'NONE' }\", \"value_template\": \"{{ value_json.text }}\""; // need to extract value of text attribute in order to be compatible with "text" device type

  std::vector<discovery_config_metadata> dcm = { refrate, siren, display };  
  return dcm;
}

std::vector<discovery_measured_diagnostic_metadata> getAllDiscoveryMeasuredDiagnosticMessagesMetadata(){
  discovery_measured_diagnostic_metadata rssi;

  rssi.device_type = "sensor";
  rssi.device_class = "";  // battery | date | duration | timestamp | ... In some cases may be "None" - https://developers.home-assistant.io/docs/core/entity/sensor/#available-device-classes    
  //rssi.state_class = "measurement";  Accept default
  rssi.diag_attr = "wifi_rssi";
  rssi.icon = "mdi:wifi-strength-2";  // https://materialdesignicons.com/
  rssi.unit = ""; // RSSI is unitless
  
  std::vector<discovery_measured_diagnostic_metadata> dmdm = { rssi };  
  return dmdm;
}

std::vector<discovery_fact_diagnostic_metadata> getAllDiscoveryFactDiagnosticMessagesMetadata(){
  discovery_fact_diagnostic_metadata ip, mac, lastboot;
  
  ip.device_type = "sensor";
  ip.diag_attr = "wifi_ip";
  ip.icon = "mdi:ip-network";  

  mac.device_type = "sensor";
  mac.diag_attr = "wifi_mac";
  mac.icon = "mdi:network-pos";  

  lastboot.device_type = "sensor";
  lastboot.diag_attr = "last_boot";
  lastboot.icon = "mdi:clock-start";    

  std::vector<discovery_fact_diagnostic_metadata> dfdm = { ip, mac, lastboot };  
  return dfdm;
}

/* If the buildShortDevicePayload() is used, and there are no config/controls that use the full device payload, then HA will never see it.
   So the full device payload is used for both kinds of discovery message. The short version is used for diagnostic messages because they 
   are always accompanied by sensor and/or control messages. */

// build discovery message - step 3 of 4
discovery_config getDiscoveryMessage(discovery_metadata disc_meta){
    return getDiscoveryMessage(disc_meta, DEVICE_ID, buildDevicePayload(DEVICE_NAME, getMAC(), DEVICE_MANUFACTURER, DEVICE_MODEL, DEVICE_VERSION), AVAILABILITY_TOPIC, STATE_TOPIC);
}

// build discovery config/control message - step 3 of 4
discovery_config getDiscoveryMessage(discovery_config_metadata disc_meta){  
  return getDiscoveryConfigMessage(disc_meta, DEVICE_ID, buildDevicePayload(DEVICE_NAME, getMAC(), DEVICE_MANUFACTURER, DEVICE_MODEL, DEVICE_VERSION), AVAILABILITY_TOPIC);
}

// build discovery measured diagnostic message - step 3 of 4
discovery_config getDiscoveryMessage(discovery_measured_diagnostic_metadata disc_meta){  
  return getDiscoveryMeasuredDiagnosticMessage(disc_meta, DEVICE_ID, buildShortDevicePayload(DEVICE_NAME, getMAC()), AVAILABILITY_TOPIC, DIAGNOSTIC_TOPIC);
}

// build discovery diagnostic fact message - step 3 of 4
discovery_config getDiscoveryMessage(discovery_fact_diagnostic_metadata disc_meta){  
  return getDiscoveryFactDiagnosticMessage(disc_meta, DEVICE_ID, buildShortDevicePayload(DEVICE_NAME, getMAC()), AVAILABILITY_TOPIC, DIAGNOSTIC_TOPIC);
}

// *****************************

/*
  Using text size = 1, fits 336 chars (21 chars over 16 lines)
  Using text size = 2, fits 80 chars (10 chars over 8 lines)
  Use '\n' to insert linefeed in string.
*/
void displayMessage(uint8_t size, const char* message){

    display.clearDisplay();

    display.setTextSize(size);
    display.setTextColor(SSD1327_WHITE);
    display.setCursor(0,0);
    display.println(message);

    display.display();
}

/*
  Title should be <= 10 chars
*/
void displayMessage(const char* title, const char* message){
    display.clearDisplay();
    
    display.setTextSize(2); // 12x16
    display.setTextColor(SSD1327_BLACK, SSD1327_WHITE); // 'inverted' text
    display.setCursor(0,0);
    display.print(title);

    display.setTextSize(1); // 6x8
    display.setTextColor(SSD1327_WHITE);    
    display.setCursor(0,17);    
    display.println(message);  

    display.display();
}

/*  
  Message will be displayed in size 1. 
  Up to 84 chars (4 full lines) can be displayed under a 96x96 graphic.
  Graphic will be centered and top-justified.

  Usage:
  displayGraphic("ABCDEFGHIJKLMNOPQRSTUVWXYZanbdefghijklmnopqrstuvwxyz0123456789_ABCDEFGHIJKLMNOPQRSTU", FIRE_BITMAP, FIRE_WIDTH, FIRE_HEIGHT);
*/
void displayGraphic(const char* message, const u_int8_t* bitmap, uint16_t bitmap_w, uint16_t bitmap_h){  
  display.clearDisplay();
  display.drawBitmap((int)((DISPLAY_WIDTH-bitmap_w)/2), 0,  bitmap, bitmap_w, bitmap_h, SSD1327_WHITE);  

  if(strlen(message)>0){ // ensure message is not null
    display.setTextSize(1); // 6x8
    display.setTextColor(SSD1327_WHITE);    
    display.setCursor(0,bitmap_h); // start text left justified under graphic   
    display.println(message);  
  }

  display.display();    
}

void displayClear(){  
  display.clearDisplay();
  display.display();    
}

void displayWifiOffline(){
  displayGraphic("Unable to connect to network!", WIFI_ALERT_BITMAP, WIFI_ALERT_WIDTH, WIFI_ALERT_HEIGHT);    
}

void displayMQTTOffline(){
  displayGraphic("Unable to connect to MQTT broker!", MQTT_ALERT_BITMAP, MQTT_ALERT_WIDTH, MQTT_ALERT_HEIGHT);    
}

void displayBroken(const char *message){
  displayGraphic(message, BROKEN_BITMAP, BROKEN_WIDTH, BROKEN_HEIGHT);    
}


/*
  This will begin playing the tone.
  With useInterrupts() functional, a hardware interrupt will cause the automatic invocation of feedBuffer().
  However, without this hardware interrupt, feedBuffer() must be explicitly called until musicPlayer.playingMusic is FALSE (see loop()).
*/
void activateSiren(const char *tone, float volume_level, int duration /*ignored*/){  
  Sprintln(F("Activate siren!"));
  Sprint("tone = "); Sprintln(tone);
  Sprint("volume_level = "); Sprintln(volume_level);
  Sprint("duration = "); Sprintln(duration);

  // VOLUME
  // Set volume for left, right channels. lower numbers == louder volume!
  uint8_t vol = 0;
  if(volume_level > 0.0){
    vol = ceil(255 * volume_level); // 1..255  where 1 is quietest, 255 loudest
    vol = 256 - vol; // 1..255  where 1 is loudest, 255 is quietest
  }  
  musicPlayer.setVolume(vol,vol);  
  Sprint("vol = "); Sprintln(vol);

  // DURATION
  //?
  
  /*
  Since the tone names are the actual filenames (restricted to 8.3 on FAT formatted SDcard), all 
  this does is prepends the directory path where the tones are stored. 

  alarm.mp3 --> /tones/alarm.mp3
  */
  String filename = TONE_DIR + String("/") + String(tone); // /tones/alarm.mp3  
     
  Sprint(F("Playing file: ")); Sprintln(filename);

  // This will starve the main loop() until the tone is completely played.
  // if(musicPlayer.playFullFile(filename)){
  //   Sprintln("play end");
  // }
  if(!musicPlayer.startPlayingFile(filename.c_str())){    
    Sprintln(F("Failed to play!"));
  }  
}


void deactivateSiren(){  
  Sprintln(F("Deactivate siren"));

  if(!musicPlayer.stopped()){
    musicPlayer.stopPlaying();
  }
}

void printDirectory(File dir, int numTabs) {
   while(true) {
     
     File entry =  dir.openNextFile();
     if (! entry) {
       // no more files
       //Serial.println("**nomorefiles**");
       break;
     }
     for (uint8_t i=0; i<numTabs; i++) {
       Serial.print('\t');
     }
     Serial.print(entry.name());
     if (entry.isDirectory()) {
       Serial.println("/");
       printDirectory(entry, numTabs+1);
     } else {
       // files have sizes, directories do not
       Serial.print("\t\t");
       Serial.println(entry.size(), DEC);
     }
     entry.close();
   }
}

void indicateSensorProblem(byte return_code){
  Sprintln(F("ERROR: Sensor problem!"));
  // ten "short" flashes for 0.5s each
  int count = 0;
  do {
      pixels.setPixelColor(0, pixels.Color(255, 0, 0)); // red
      pixels.show();   // Send the updated pixel colors to the hardware.
      delay(500); 
  } 
  while(count < 10);  
  pixels.clear();
}

// https://stackoverflow.com/questions/4668760/converting-an-int-to-stdstring
std::string to_string( int x ) {
  int length = snprintf( NULL, 0, "%d", x );
  assert( length >= 0 );
  char* buf = new char[length + 1];
  snprintf( buf, length + 1, "%d", x );
  std::string str( buf );
  delete[] buf;
  return str;
}

/**
 * @brief Convert a float to a std::string
 * 
 * @param x float to be formatted and converted to std::string
 * @param format Should be related to float like "%4.2f" or "%3.1g"
 * @return std::string 
 */
std::string to_string( float x, const char* format) {
  int length = snprintf( NULL, 0, format, x );
  assert( length >= 0 );
  char* buf = new char[length + 1];
  snprintf( buf, length + 1, format, x );
  std::string str( buf );
  delete[] buf;
  return str;
}

/*
  temperature                         : sensor on BME280 in celcius
  humidity                            : sensor on BME280 in %RH
  pressure                            : sensor on BME280 is atmospheric pressure in hectopascal (hPa)
*/
void publishSensorData(){
  
      std::string payload = "{\
\"temperature\": "+to_string(bme.readTemperature(), "%2.2f")+", \
\"humidity\": "+to_string(bme.readHumidity(), "%2.2f")+", \
\"pressure\": "+to_string((bme.readPressure() / 100.0F), "%5.1f")+" \
}";

      const char* payload_ch = payload.c_str();

      Sprint(F("Publishing sensor readings: "));  
      Sprintln(payload_ch);
      mqttclient.publish(STATE_TOPIC.c_str(), payload_ch, NOT_RETAINED, QOS_0);  
}
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
void loop()
{
  if(musicPlayer.playingMusic) {
    lastPlayingState = true;
    pixels.setPixelColor(0, pixels.Color(128, 128, 0)); // gold
    pixels.show();    
    musicPlayer.feedBuffer();
    //Sprint(">");
    pixels.clear();
    pixels.show();    
  }
  else{
    if(lastPlayingState){ // just finished playing

      // update the state to indicate that the device is no longer playing a tone.
      // when a deactivateSiren() call is made, it will already publish an updated state; but no harm in a duplicated OFF state update.
      std::string payload = "{\"state\": \""+OFF_VALUE+"\"}";
      publish(STATE_TOPIC.c_str(), payload.c_str());

      lastPlayingState = false;
    }
  }
  
  assertConnectivity(); // Blocks until network and MQTT broker connectivity established and all subscriptions successful

  mqttclient.loop(); // potential call to messageReceived()
  processMessages(); // deal with any pending_ops added by messageReceived() handler
    
  if (millis() - lastMillis > refresh_rate) {   
    lastMillis = millis();
      
    pixels.setPixelColor(0, pixels.Color(0, 128, 0)); // green
    pixels.show();

    publish();

    //std::string diagnostic_message = "RSSI: "+to_string(getRSSI())+"\nIP: "+getIP()+"\nMAC:"+getMAC()+"\nBoot:\n"+lastboot;
    //displayMessage("DIAGNOSTIC", diagnostic_message.c_str());
      
    pixels.clear();
    pixels.show();        
  }    
  yield();
}

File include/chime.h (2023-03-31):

/*
    Contains hardware specific information for the base microcontroller board used. 
*/
#ifndef CHIME_H
#define CHIME_H

//#include <Arduino.h>  appears to be automatically added by framework specified in platformio.ini
#include <Arduino.h>

// #include "soc/soc.h"            // brownout detector
// #include "soc/rtc_cntl_reg.h"   // brownout detector

#include <ArduinoJson.h>

#include <SPI.h>
#include <SD.h>
#include <Adafruit_VS1053.h>

#include <Wire.h>
#include <Adafruit_Sensor.h>
#include <Adafruit_BME280.h>

#include <Adafruit_NeoPixel.h>

#include <Adafruit_SSD1327.h>

#include "wifi-helper.h"
#include "mqtt-ha-helper.h"
#include "env.h"
#include "log.h"
#include "esp32_util.h"

// board has a single neopixel
#define NUMPIXELS 1

// https://www.adafruit.com/product/3357
#define VS1053_RESET   -1     // VS1053 reset pin (not used!) - reset is linked to microcontroller reset
#define VS1053_CS       6     // VS1053 chip select pin (output)
#define VS1053_DCS     10     // VS1053 Data/command select pin (output)
#define CARDCS          5     // Card chip select pin
// DREQ should be an Int pin *if possible* (not possible on 32u4)
#define VS1053_DREQ     9     // VS1053 Data request, ideally an Interrupt pin

#define DEVICE_ID "featheresp32s2"
#define DEVICE_NAME "Chime"
#define DEVICE_MANUFACTURER "Adafruit"
#define DEVICE_MODEL "Feather ESP32-S2 with BME280"
#define DEVICE_VERSION "20230331.0900"

// Directory on SDcard where tones are stored. 
#define TONE_DIR "/tones"

// Display
// Used for I2C or SPI
#define OLED_RESET -1
#define DISPLAY_WIDTH 128
#define DISPLAY_HEIGHT 128

// ***
// These graphics below are internal to the device and are used exclusively to indicate device status such as wifi or MQTT broker 
// disconnect or some internal component initialization problem. They are not among the list of graphics that can be set via MQTT.

#define WIFI_ALERT_HEIGHT 96
#define WIFI_ALERT_WIDTH 96

// array size is 1152
static const unsigned char WIFI_ALERT_BITMAP[] PROGMEM  = {
  B00000000, B00000000, B00000000, B00000000, B00000000, B00000000, B00000000, B00000000, B00000000, B00000000, B00000000, B00000000, 
  B00000000, B00000000, B00000000, B00000000, B00000000, B00000000, B00000000, B00000000, B00000000, B00000000, B00000000, B00000000, 
  B00000000, B00000000, B00000000, B00000000, B00000000, B00000000, B00000000, B00000000, B00000000, B00000000, B00000000, B00000000, 
  B00000000, B00000000, B00000000, B00000000, B00000000, B00000000, B00000000, B00000000, B00000000, B00000000, B00000000, B00000000, 
  B00000000, B00000000, B00000000, B00000000, B00000000, B00000000, B00000000, B00000000, B00000000, B00000000, B00000000, B00000000, 
  B00000000, B00000000, B00000000, B00000000, B00000000, B00000000, B00000000, B00000000, B00000000, B00000000, B00000000, B00000000, 
  B00000000, B00000000, B00000000, B00000000, B00000000, B00000000, B00000000, B00000000, B00000000, B00000000, B00000000, B00000000, 
  B00000000, B00000000, B00000000, B00000000, B00000000, B00000000, B00000000, B00000000, B00000000, B00000000, B00000000, B00000000, 
  B00000000, B00000000, B00000000, B00000000, B00000000, B00000000, B00000000, B00000000, B00000000, B00000000, B00000000, B00000000, 
  B00000000, B00000000, B00000000, B00000000, B00000000, B00000000, B00000000, B00000000, B00000000, B00000000, B00000000, B00000000, 
  B00000000, B00000000, B00000000, B00000000, B00000000, B00000000, B00000000, B00000000, B00000000, B00000000, B00000000, B00000000, 
  B00000000, B00000000, B00000000, B00000000, B00000000, B00000000, B00000000, B00000000, B00000000, B00000000, B00000000, B00000000, 
  B00000000, B00000000, B00000000, B00000000, B00000000, B01111111, B11111110, B00000000, B00000000, B00000000, B00000000, B00000000, 
  B00000000, B00000000, B00000000, B00000000, B00111111, B11111111, B11111111, B11111100, B00000000, B00000000, B00000000, B00000000, 
  B00000000, B00000000, B00000000, B00000111, B11111111, B11111111, B11111111, B11111111, B11100000, B00000000, B00000000, B00000000, 
  B00000000, B00000000, B00000000, B00111111, B11111111, B11111111, B11111111, B11111111, B11111100, B00000000, B00000000, B00000000, 
  B00000000, B00000000, B00000001, B11111111, B11111111, B11111111, B11111111, B11111111, B11111111, B10000000, B00000000, B00000000, 
  B00000000, B00000000, B00001111, B11111111, B11111111, B11111111, B11111111, B11111111, B11111111, B11100000, B00000000, B00000000, 
  B00000000, B00000000, B00111111, B11111111, B11111111, B11111111, B11111111, B11111111, B11111111, B11111100, B00000000, B00000000, 
  B00000000, B00000000, B11111111, B11111111, B11111111, B11111111, B11111111, B11111111, B11111111, B11111111, B00000000, B00000000, 
  B00000000, B00000011, B11111111, B11111111, B11111111, B11111111, B11111111, B11111111, B11111111, B00000000, B00000000, B00000000, 
  B00000000, B00001111, B11111111, B11111111, B11111111, B11111111, B11111111, B11111111, B11111111, B00000000, B00000000, B00000000, 
  B00000000, B00011111, B11111111, B11111111, B11111111, B11111111, B11111111, B11111111, B11111111, B00000000, B00000000, B00000000, 
  B00000000, B01111111, B11111111, B11111111, B11111111, B11111111, B11111111, B11111111, B11111111, B00000000, B00000000, B00000000, 
  B00000000, B11111111, B11111111, B11111111, B11111111, B10000000, B00000001, B11111111, B11111111, B00000000, B00000000, B00000000, 
  B00000011, B11111111, B11111111, B11111111, B11100000, B00000000, B00000000, B00000111, B11111111, B00000000, B00000000, B00000000, 
  B00000111, B11111111, B11111111, B11111110, B00000000, B00000000, B00000000, B00000000, B01111111, B00000000, B00000000, B00000000, 
  B00000011, B11111111, B11111111, B11110000, B00000000, B00000000, B00000000, B00000000, B00001111, B00000000, B00000000, B00000000, 
  B00000011, B11111111, B11111111, B10000000, B00000000, B00000000, B00000000, B00000000, B00000001, B00000000, B11111111, B00000000, 
  B00000001, B11111111, B11111110, B00000000, B00000000, B00000000, B00000000, B00000000, B00000000, B00000000, B11111111, B00000000, 
  B00000000, B11111111, B11111000, B00000000, B00000000, B00000000, B00000000, B00000000, B00000000, B00000000, B11111111, B00000000, 
  B00000000, B01111111, B11100000, B00000000, B00000000, B00000000, B00000000, B00000000, B00000000, B00000000, B11111111, B00000000, 
  B00000000, B01111111, B10000000, B00000000, B00000000, B00000000, B00000000, B00000000, B00000000, B00000000, B11111111, B00000000, 
  B00000000, B00111111, B00000000, B00000000, B00000000, B00000000, B00000000, B00000000, B00000000, B00000000, B11111111, B00000000, 
  B00000000, B00011100, B00000000, B00000000, B00000000, B00000000, B00000000, B00000000, B00000000, B00000000, B11111111, B00000000, 
  B00000000, B00001000, B00000000, B00000000, B00000000, B00000000, B00000000, B00000000, B00000000, B00000000, B11111111, B00000000,
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
